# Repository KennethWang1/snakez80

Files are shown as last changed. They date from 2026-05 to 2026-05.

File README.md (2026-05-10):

# snakez80

Snake running on a custom Z80 computer. Made for TEJ4MP.

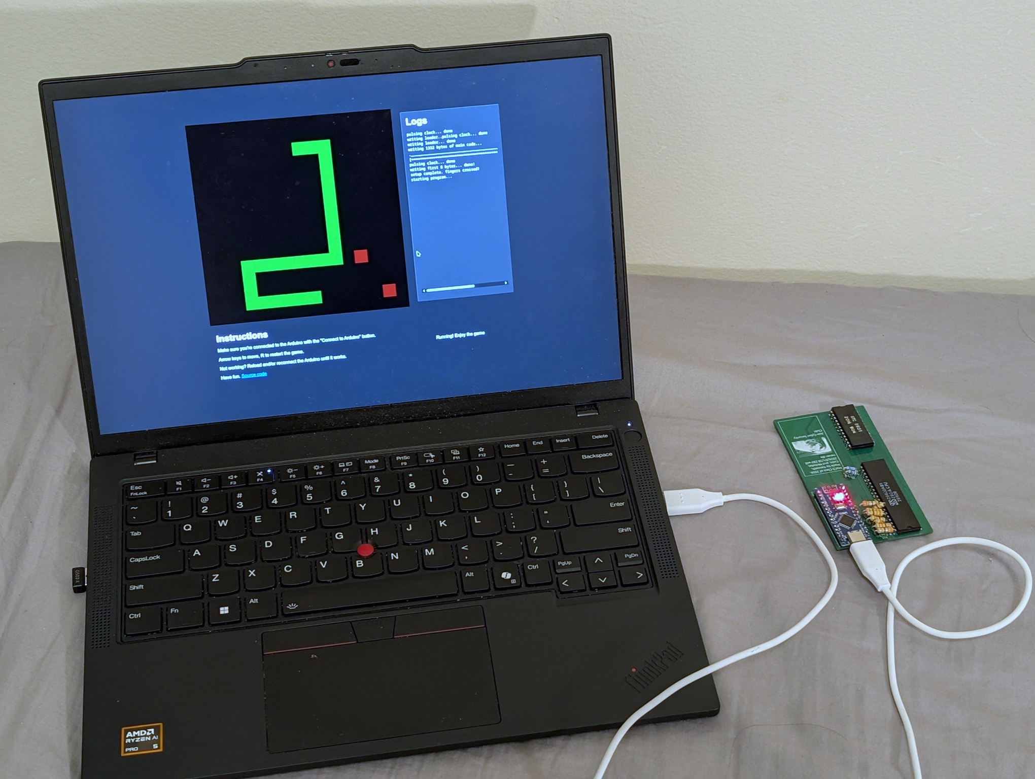
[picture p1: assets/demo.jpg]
Snake Demo


# Requirements

- A Z8400-compatible CPU.
- A TMM2016BP memory chip or compatible.
- A PCB with the KiCAD design (TODO: add link to kicad design), or a breadboard with the equivalent schematic.
- An Arduino Nano.

Connect everything, flash the [loader code](./loader) with the Arduino IDE, and open [`web/index.html`](web/index.html) or https://creative0708.github.io/snakez80/ in a browser.

Have fun.

# Building `rom.hpp` from source

You'll need a set of [z88dk](https://github.com/z88dk/z88dk) binaries **with** SDCC. Follow its [installation instructions](https://github.com/z88dk/z88dk/wiki/installation) to install it.

Run `make` to build the ROM and convert the ROM into Arduino code.

# License

If for some reason you want to use this code, it's licensed under the [MIT License](/LICENSE).

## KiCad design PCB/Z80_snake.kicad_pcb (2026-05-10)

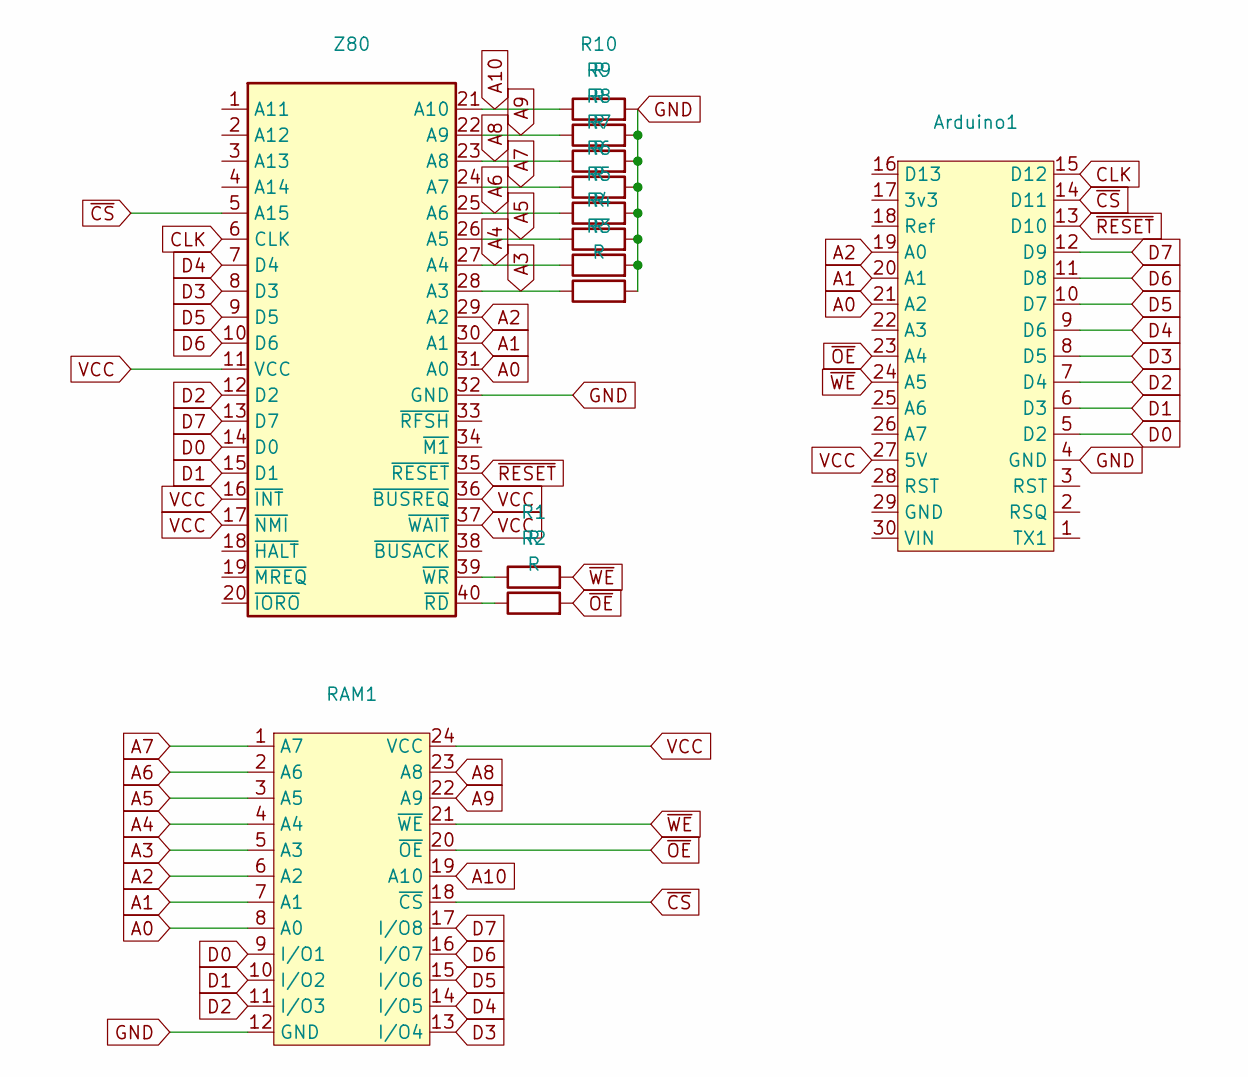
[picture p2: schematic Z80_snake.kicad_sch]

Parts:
Arduino1: Arduino_Nano
R1, R2, R3, R4, R5, R6, R7, R8, R9, R10: R; R_Axial_DIN0204_L3.6mm_D1.6mm_P7.62mm_Horizontal
RAM1: RAM
Z80: Z8400AB1

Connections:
A0: Arduino1.21 (A2), RAM1.8 (A0), Z80.31 (A0)
A1: Arduino1.20 (A1), RAM1.7 (A1), Z80.30 (A1)
A2: Arduino1.19 (A0), RAM1.6 (A2), Z80.29 (A2)
A3: R3.1, RAM1.5 (A3), Z80.28 (A3)
A4: R4.1, RAM1.4 (A4), Z80.27 (A4)
A5: R5.1, RAM1.3 (A5), Z80.26 (A5)
A6: R6.1, RAM1.2 (A6), Z80.25 (A6)
A7: R7.1, RAM1.1 (A7), Z80.24 (A7)
A8: R8.1, RAM1.23 (A8), Z80.23 (A8)
A9: R9.1, RAM1.22 (A9), Z80.22 (A9)
A10: R10.1, RAM1.19 (A10), Z80.21 (A10)
CLK: Arduino1.15 (D12), Z80.6 (CLK)
D0: Arduino1.5 (D2), RAM1.9 (I/O1), Z80.14 (D0)
D1: Arduino1.6 (D3), RAM1.10 (I/O2), Z80.15 (D1)
D2: Arduino1.7 (D4), RAM1.11 (I/O3), Z80.12 (D2)
D3: Arduino1.8 (D5), RAM1.13 (I/O4), Z80.8 (D3)
D4: Arduino1.9 (D6), RAM1.14 (I/O5), Z80.7 (D4)
D5: Arduino1.10 (D7), RAM1.15 (I/O6), Z80.9 (D5)
D6: Arduino1.11 (D8), RAM1.16 (I/O7), Z80.10 (D6)
D7: Arduino1.12 (D9), RAM1.17 (I/O8), Z80.13 (D7)
GND: Arduino1.4 (GND), R3.2, R4.2, R5.2, R6.2, R7.2, R8.2, R9.2, R10.2, RAM1.12 (GND), Z80.32 (GND)
unnamed: R2.1, Z80.40 (~RD)
unnamed: R1.1, Z80.39 (~WR)
VCC: Arduino1.27 (5V), RAM1.24 (VCC), Z80.11 (VCC), Z80.16 (~INT), Z80.17 (~NMI), Z80.36 (~BUSREQ), Z80.37 (~WAIT)
~CS: Arduino1.14 (D11), RAM1.18 (~CS), Z80.5 (A15)
~OE: Arduino1.23 (A4), R2.2, RAM1.20 (~OE)
~RESET: Arduino1.13 (D10), Z80.35 (~RESET)
~WE: Arduino1.24 (A5), R1.2, RAM1.21 (~WE)

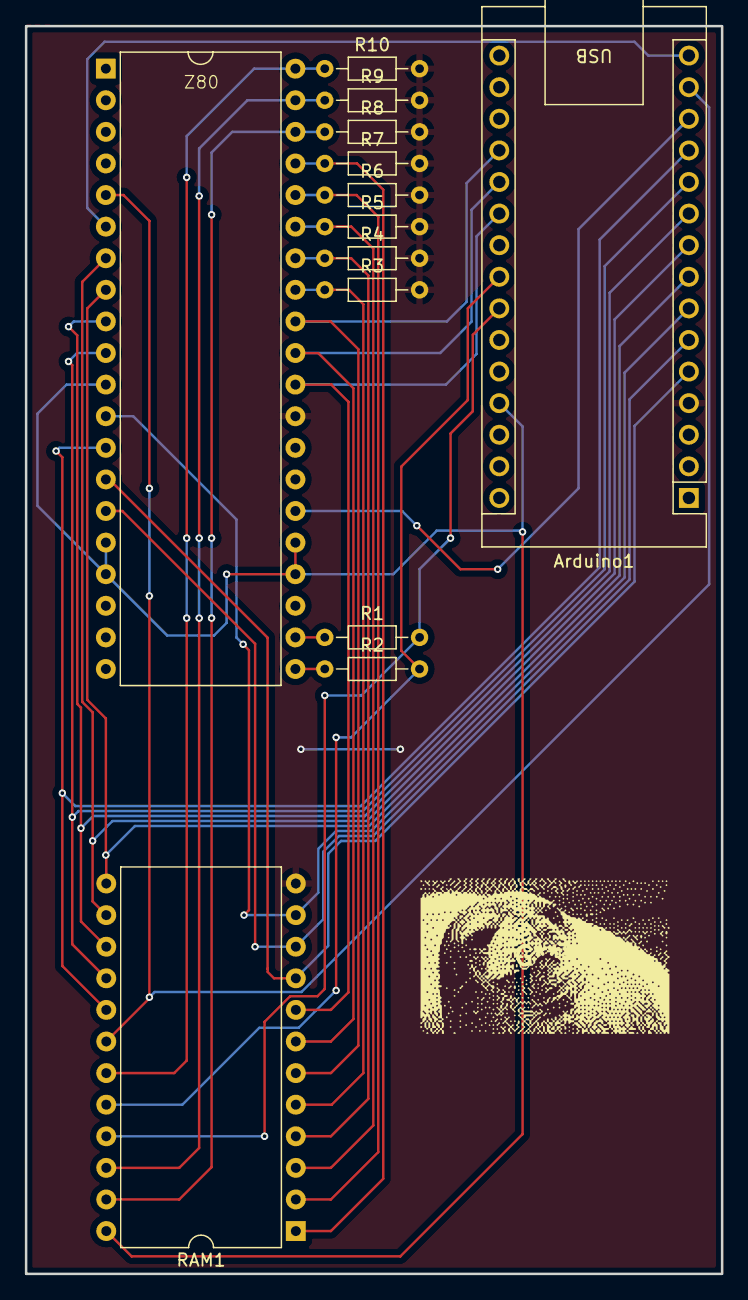
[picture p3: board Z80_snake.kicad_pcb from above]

Board: 2 copper layers, 55.9 x 100.3 mm, 13 parts (0 on the bottom side), 28 nets.

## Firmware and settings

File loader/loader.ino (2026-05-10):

#include "rom.hpp"

char loader[8];
/*
8 byte initial instructions for the CPU.
generated from `loader.asm` with `make`.
*/
const char INITIAL_LOADER[8] = "\x21\x00\x00\x7e\x23\xc3\x03\x00";

// define the purpuse of various pins
#define Z80_RST 10
#define Z80_CLK 12
#define COM_RE A4
#define COM_WE A5
#define COM_CS 11
#define DATA_START 2

// various other variables
#define CS_ARDUINO HIGH
#define CS_RAM LOW

// clock delays
unsigned long PULSE_DELAY = 2;
unsigned long PULSE_WAIT = 2;

const unsigned int FPS = 16;

inline void delayPulseWait() { delayMicroseconds(PULSE_WAIT); }
inline void delayPulseDelay() { delayMicroseconds(PULSE_DELAY); }

// helper code to pulse a pin
void digitalPulse(int pin, int signal) {
  delayPulseWait();
  digitalWrite(pin, signal);
  delayPulseDelay();
  digitalWrite(pin, !signal);
  delayPulseWait();
}

// assigns the 8 data pins a given pinmode
void dataPinMode(int pinmode) {
  for (int bit = 0; bit < 8; bit++)
    pinMode(DATA_START + bit, pinmode);
}

// assigns the 3 address pins a certain pinmode as well as the chip select
void addressPinMode(int pinmode) {
  for (int bit = 0; bit < 3; bit++)
    pinMode(addressPin(bit), pinmode);
  pinMode(COM_CS, pinmode);
}

// write a byte to the data lines
void writeByte(uint8_t byte) {
  for (int bit = 0; bit < 8; bit++)
    digitalWrite(DATA_START + bit, bitRead(byte, bit));
}

// read and return a byte from the data lines
uint8_t readByte() {
  uint8_t byte = 0;
  for (int bit = 0; bit < 8; bit++)
    byte |= digitalRead(DATA_START + bit) << bit;
  return byte;
}

// get the pin number of the ith addr pin
constexpr int addressPin(int bit) { return A2 - bit; }

// read the addr from the addr pins
int8_t readAddress() {
  int8_t res = 0;
  for (int bit = 0; bit < 3; bit++)
    res |= digitalRead(addressPin(bit)) << bit;
  return res;
}

void die() {
  while (1)
    delay(1000);
}

// write loader program, then verifies it
void writeLoader() {
  // set necessary pinmodes to output
  addressPinMode(OUTPUT);
  dataPinMode(OUTPUT);
  pinMode(COM_RE, OUTPUT);
  pinMode(COM_WE, OUTPUT);
  pinMode(LED_BUILTIN, OUTPUT);
  digitalWrite(LED_BUILTIN, HIGH);

  // loops until the loader program is verified
  while (1) {
    // sets data pins to output
    dataPinMode(OUTPUT);

    // disables all pins
    digitalWrite(COM_RE, HIGH);
    digitalWrite(COM_WE, HIGH);
    // enables chip select
    digitalWrite(COM_CS, CS_RAM);

    // writes the loader program
    for (int i = 0; i < 8; i++) {
      for (int bit = 0; bit < 3; bit++)
        // sets correct addr
        digitalWrite(addressPin(bit), i >> bit & 1);
      // writes the byte
      writeByte((uint8_t)loader[i]);
      // pulses the WE pin so that the ram writes the data into its memory
      digitalPulse(COM_WE, LOW);
    }
    // sets all data pins to input
    dataPinMode(INPUT);
    // if loader program is verified, break
    // otherwise rewrite the loader program until it works
    if (verifyLoader())
      break;
  }
  // reset the pinmodes
  addressPinMode(INPUT);
  dataPinMode(INPUT);
  pinMode(COM_RE, INPUT);
  pinMode(COM_WE, INPUT);
}

// verifies the loader program has been correctly loaded into ram
bool verifyLoader() {
  // enables chip select
  digitalWrite(COM_CS, CS_RAM);
  // disables all pins
  digitalWrite(COM_RE, HIGH);
  digitalWrite(COM_WE, HIGH);

  int valid = true;

  // loops through loader program to verify it has been loaded correctly
  for (int i = 0; i < 8; i++) {
    // sets all addr pins correctly
    for (int bit = 0; bit < 3; bit++)
      digitalWrite(addressPin(bit), i >> bit & 1);
    delayPulseWait();
    // signals the ram to output the data at the given byte
    digitalWrite(COM_RE, LOW);
    delayPulseDelay();
    // reads the data
    uint8_t read = readByte();
    // gets what the expected byte is
    uint8_t expected = loader[i];
    // if the read and expected data do not match, mark as invalid
    if (expected != read)
      valid = false;

    digitalWrite(COM_RE, HIGH);
    delayPulseWait();
  }

  // Serial.print("loader verification ");
  // if(valid){
  //   Serial.println("passed");
  // }else {
  //   Serial.println("failed");
  // }

  // returns whether the loader program is valid
  return valid;
}

void disableCpu() {
  digitalWrite(Z80_RST, LOW);
  digitalWrite(Z80_CLK, HIGH);
  delay(10);

  // pulses clock an arbitray number of times (>3 as per datasheet) to ensure
  // the CPU is finished its reset cycle
  Serial.print("pulsing clock...");
  for (int i = 0; i < 20; i++)
    digitalPulse(Z80_CLK, HIGH);
  Serial.println(" done");
  digitalWrite(Z80_CLK, LOW);
}

void enableCpu() { digitalWrite(Z80_RST, HIGH); }

long clockCycle = 0;

int8_t prevReadAddr = -1;

unsigned long nextFrameTime = 0;

// setup function which runs when the arduino starts
void setup() {
  Serial.begin(115200);

  // sets data pins, reset and clock to the correct pinmodes
  pinMode(Z80_RST, OUTPUT);
  pinMode(Z80_CLK, OUTPUT);
  pinMode(COM_RE, INPUT);
  pinMode(COM_WE, INPUT);
  pinMode(COM_CS, INPUT);
  dataPinMode(INPUT);
  addressPinMode(INPUT);

  // disable cpu
  disableCpu();

  // write loader code
  Serial.print("writing loader...");
  memcpy(loader, INITIAL_LOADER, sizeof(loader));
  writeLoader();
  Serial.println(" done");

  const int PROGRESS_WIDTH = 64;

  // enable cpu
  enableCpu();

  Serial.print("writing ");
  Serial.print(sizeof(FULL_CODE) - 8);
  Serial.println(" bytes of main code...");
  Serial.print(".");
  for (int i = 0; i < PROGRESS_WIDTH; i++) {
    Serial.print("_");
  }
  Serial.println(".");

  // pulse the clock until the cpu enters the main loop
  for (int i = 0; i < 17; i++) {
    digitalPulse(Z80_CLK, HIGH);
  }

  Serial.print("[");
  int prev_indicator_pos = 0;
  // main loader loop!
  for (uint16_t addr = 0; addr < sizeof(FULL_CODE); addr++) {
    int8_t curAddr = readAddress();
    if (curAddr != (addr & 7)) {
      Serial.print("invalid addr encountered! expected ");
      Serial.print((int)addr & 7);
      Serial.print(", got ");
      Serial.println(curAddr);
      die();
    }
    // it is expected that the CPU is putting the required addr on the addr
    // lines, verify it
    if (digitalRead(COM_RE)) {
      Serial.println("expected cpu to read on this clock cycle!");
      Serial.print("addr: ");
      Serial.println(addr);
      die();
    }

    uint8_t code_value = pgm_read_byte_near(&FULL_CODE[addr]);

    // only override the addr if it would not otherwise override the loader code
    if (addr >= 8) {
      // override the CPU's RE and WE; because there are resistors on the CPU
      // side this is fine
      pinMode(COM_RE, OUTPUT);
      pinMode(COM_WE, OUTPUT);
      digitalWrite(COM_RE, HIGH);
      digitalWrite(COM_WE, HIGH);
      dataPinMode(OUTPUT);
      writeByte(code_value);
      // and write the data!
      digitalPulse(COM_WE, LOW);
      pinMode(COM_RE, INPUT);
      pinMode(COM_WE, INPUT);
      dataPinMode(INPUT);
    }

    // the cpu reads twice; use this to verify that the previous data was
    // written correctly
    digitalPulse(Z80_CLK, HIGH);
    uint8_t expected_value = addr < 8 ? loader[addr] : code_value;
    uint8_t actual_value = readByte();

    if (actual_value != expected_value) {
      Serial.print("invalid data encountered at ");
      Serial.print(addr);
      Serial.print(": expected ");
      Serial.print(expected_value);
      Serial.print(", got ");
      Serial.println(actual_value);
      die();
    }

    // advance to the next cycle
    for (int i = 0; i < 22; i++)
      digitalPulse(Z80_CLK, HIGH);

    int new_indicator_pos =
        (long)(addr + 1) * PROGRESS_WIDTH / sizeof(FULL_CODE);

    // loading indicator
    for (; prev_indicator_pos < new_indicator_pos; prev_indicator_pos++) {
      Serial.print("=");
    }
  }
  Serial.println("]");

  disableCpu();

  Serial.print("writing first 8 bytes...");
  // memcpy(loader, FULL_CODE, sizeof(loader)); doesn't work because FULL_CODE
  // is PROGMEM
  for (int i = 0; i < 8; i++)
    loader[i] = pgm_read_byte_near(&FULL_CODE[i]);

  writeLoader();
  Serial.println(" done!");

  enableCpu();

  Serial.println("setup complete. fingers crossed!");

  Serial.println("starting program...");

  nextFrameTime = micros();

  PULSE_DELAY = PULSE_WAIT = 1UL;
}

// converts an integer (0 to 15) to the respective hex character
char hexToChar(uint8_t c) {
  if (c <= 9)
    return c + '0';
  else
    return c - 10 + 'a';
}

char fb_queue[256];
uint8_t fbptr = 0;

inline void clockPulse() {
  u8 readPort = PORTB;
  PORTB = readPort | (1 << Z80_CLK - 8);

  __asm__("nop");
  __asm__("nop");
  __asm__("nop");
  __asm__("nop");
  __asm__("nop");

  PORTB = readPort;
}
inline byte readRwPins() {
  return digitalRead(COM_WE) << 1 | digitalRead(COM_RE);
  // return PINC >> COM_RE - 16 & 0b11;
}
inline bool readCs() { return PINB & 1 << COM_CS - 8; }

// main loop program which runs after setup finishes
void loop() {
  clockPulse();

  bool arduino_enabled = readCs() == CS_ARDUINO;
  byte rw;
  if (!arduino_enabled || (rw = readRwPins()) == 0b11) {
    if (prevReadAddr != -1) {
      // set data pin modes to input once the cpu has finished reading
      dataPinMode(INPUT);
      prevReadAddr = -1;
    }
    return;
  }

  if ((rw & 0b10) == 0) {
    int8_t addr = readAddress();
    if (addr == 0) {
      fb_queue[fbptr++] = readByte();
    } else if (addr == 1) {
      Serial.write('\e');
      Serial.write(fb_queue, sizeof(fb_queue));
      fbptr = 0;
    } else {
      Serial.print("warning: writing to address ");
      Serial.print(addr);
      Serial.print(" ( data ");
      Serial.print(readByte());
      Serial.println(") not implemented");
    }
  } else if ((rw & 0b01) == 0) {
    int8_t addr = readAddress();
    if (prevReadAddr == addr) {
      // pins are already set; no need to re-output to the data lines
      return;
    }
    prevReadAddr = addr;

    dataPinMode(OUTPUT);

    uint8_t output_byte = 0x76;
    if (addr == 0) {
      // key available
      output_byte = Serial.available() > 0;
    } else if (addr == 1) {
      int input_key = -1;
      while (Serial.available()) {
        input_key = Serial.read();
        // special case: reset everything if we signaled 'r'
        if (input_key == 'r') {
          setup();
          return;
        }
      }
      output_byte = input_key;
    } else {
      Serial.print("warning: reading from address ");
      Serial.print(addr);
      Serial.println(" not implemented");
    }
    writeByte(output_byte);
  } else {
    Serial.println("unreachable");
    die();
  }
}

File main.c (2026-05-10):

#include <stdint.h>
#include <string.h>

typedef uint8_t u8;
typedef int8_t i8;
typedef uint16_t u16;
typedef int16_t i16;
typedef _Bool bool;
#define false 0
#define true 1

static inline bool key_available(void) {
  volatile const u8 *key_avail = (void *)0x8000;
  return *key_avail;
}
static inline u8 get_key(void) {
  volatile const u8 *key = (void *)0x8001;
  return *key;
}
static inline void write_pixel(u8 color) {
  volatile u8 *pixel = (void *)0x8000;
  *pixel = color;
}
static inline void wait_for_next_frame(void) {
  volatile u8 *key = (void *)0x8001;
  *key = 0;
}
static inline void debug(u8 c) {
  volatile u8 *dbg = (void *)0x8007;
  *dbg = c;
}

u16 random_seed = 0x9f63;
static u16 random_u16(void) {
  u16 x = random_seed;
  x ^= x << 7;
  x ^= x >> 9;
  x ^= x << 3;
  return random_seed = x;
}

#define Y_SHIFT 4
#define COORD(x, y) ((y) << Y_SHIFT | (x))
#define COORD_X(coord) (((u8)(coord)) & (1 << Y_SHIFT) - 1)
#define COORD_Y(coord) (((u8)(coord)) >> Y_SHIFT)

enum Color {
  COLOR_BLACK = 0,
  COLOR_WHITE = 1,
  COLOR_GREEN = 2,
  COLOR_RED = 3,
};

#define MAX_NUM_APPLES 4
u8 num_apples = 2;
u8 apple_coords[MAX_NUM_APPLES];

bool dead = false;

const i8 DIR[4] = {-COORD(1, 0), COORD(0, 1), COORD(1, 0), -COORD(0, 1)};
i8 snake_dir = COORD(1, 0); // right

#define INPUT_QUEUE_SIZE 2
i8 input_queue[INPUT_QUEUE_SIZE];
u8 input_queue_pos = 0;

const u8 SNAKE_MOVEMENT_FRAMES = 3;
u8 movement_counter = 0;

// deque
u8 snake_head = 0;
u16 snake_len = 3;
u8 snake_coords[256] = {COORD(3, 1), COORD(2, 1), COORD(1, 1)};
u8 grid_colors[256];

static inline void halt(void) { __asm__("halt"); }

static void render_frame(void) {
  memset(grid_colors, COLOR_BLACK, sizeof(grid_colors));

  // this loop is very inefficient and visibly slows the game down
  // but i can't be bothered to fix it right now (or ever, actually)
  u8 snake_color = COLOR_GREEN;
  for (int i = snake_head, end = snake_head + snake_len; i < end; i++) {
    u8 idx = snake_coords[(u8)i];
    if (grid_colors[idx] != COLOR_BLACK) {
      // snake collided with itself
      dead = true;
    }
    grid_colors[idx] = snake_color;
  }
  for (u8 i = 0; i < num_apples; i++)
    grid_colors[apple_coords[i]] = COLOR_RED;

  if (dead) {
    const u16 PIXELS[5] = {
        0b1100111011000001, 0b1010100010101010, 0b1010110010100010,
        0b1010100010101010, 0b1100111011000001,
    };
    for (int y = 0; y < 5; y++) {
      u16 row = PIXELS[y];
      for (int x = 0; x < 16; x++) {
        if (row >> (15 - x) & 1)
          grid_colors[COORD(x, y + 6)] = COLOR_WHITE;
      }
    }
  }

  for (u16 i = 0; i < 256; i++)
    write_pixel(grid_colors[i]);
}

static void handle_key_events(void) {
  if (!key_available())
    return;
  // insert new_dir at position 0
  if (input_queue_pos == INPUT_QUEUE_SIZE)
    input_queue_pos--;
  for (int i = input_queue_pos; i > 0; i--)
    input_queue[i] = input_queue[i - 1];
  input_queue_pos++;
  i8 direction = DIR[get_key() & 3];
  input_queue[0] = direction;
  // seed rng
  random_seed ^= direction;
  random_u16();
  random_u16();
  random_u16();
}

static void tick_snake(void) {
  if (input_queue_pos) {
    i8 new_dir = input_queue[--input_queue_pos];
    if (new_dir != -snake_dir)
      snake_dir = new_dir;
  }

  u8 head_coord = snake_coords[snake_head];
  // sign-extend snake_dir
  i16 direction = snake_dir;
  u16 new_coord = head_coord + direction;
  // bounds checks
  if ((snake_dir & 1) != 0) {
    // direction in x, if y values are different then we overflowed
    if (COORD_Y(new_coord) != COORD_Y(head_coord))
      dead = true;
  } else {
    // direction in y, straightforward overflow check
    if (new_coord & 0xff00)
      dead = true;
  }
  if (dead)
    return;

  // since everything is a u8, we get wrapping arithmetic for free
  snake_head--;
  snake_coords[snake_head] = new_coord;

  for (int i = 0; i < num_apples; i++) {
    if (apple_coords[i] == new_coord) {
      // ate apple!
      snake_len++;
      // use previous frame's grid to place new apple; this is not perfect
      // but it works well enough
      u8 new_apple_coord;
      do {
        new_apple_coord = random_u16();
      } while (grid_colors[new_apple_coord] != COLOR_BLACK);
      apple_coords[i] = new_apple_coord;
    }
  }
}

int main(void) {
  memset(grid_colors, COLOR_BLACK, sizeof(grid_colors));
  for (int i = 0; i < num_apples; i++)
    apple_coords[i] = random_u16();

  while (1) {
    handle_key_events();
    if (!dead) {
      if (++movement_counter == SNAKE_MOVEMENT_FRAMES) {
        movement_counter = 0;
        tick_snake();
      }
    }
    render_frame();
    wait_for_next_frame();
  }
}
